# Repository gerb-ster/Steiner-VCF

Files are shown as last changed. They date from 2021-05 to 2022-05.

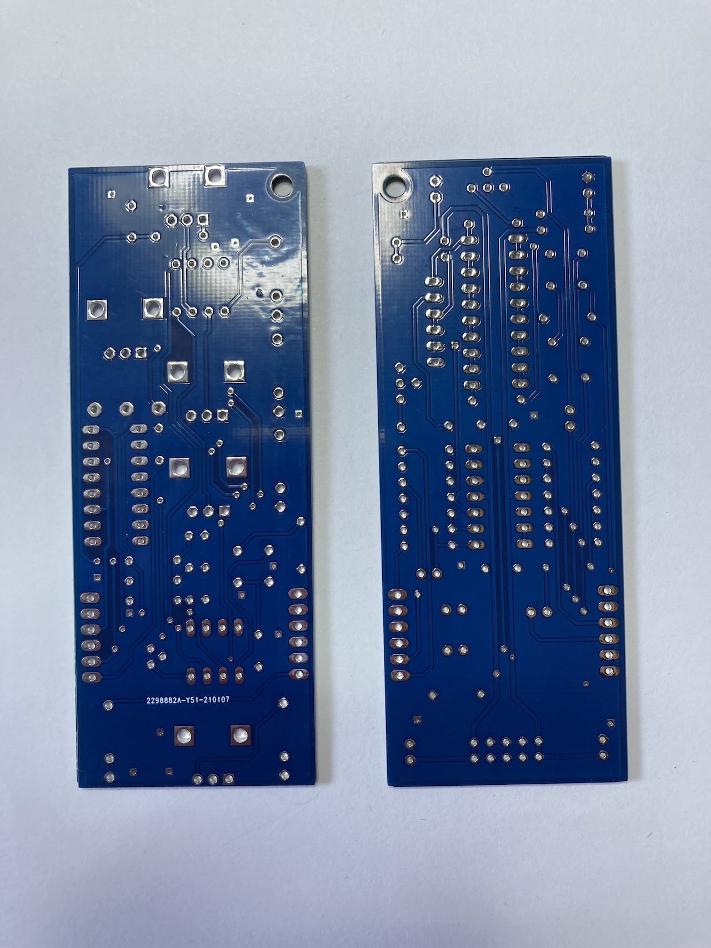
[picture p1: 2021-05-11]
images/IMG_3992.jpeg

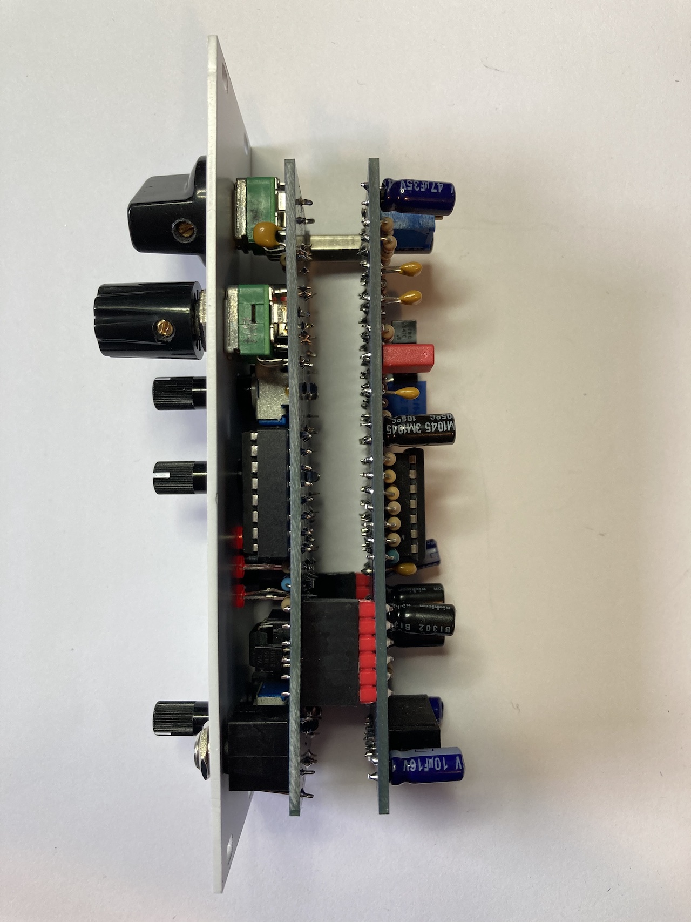
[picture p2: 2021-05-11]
images/IMG_4002.jpeg

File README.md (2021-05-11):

# YUSynth Steiner VCF

Another one of the wonderful VCF designs from YuSynth. The VCF ‘core’ is the same as the design from YuSynth, I just replaced the rotary switch with a ‘digital’ version controlled by a Atmel ATTINY22 and a ADG412 digital SPST switch. This allows you to select 2 more modes, namely HP+BP and LP+BP, next to HP, BP, LP and AP (LP+BP+HP).

The original design:

http://yusynth.net/Modular/EN/STEINERVCF/index-v2.html

## Status: Work in Progress

- done: first schematic & board design
- done: breadboard and test
- done: design frontpanel
- done: order PCB and build prototype
- todo: final debugging
- todo: rewrite the firmware in pure C

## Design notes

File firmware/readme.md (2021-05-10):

## Firmware

The ATTiny IC is loaded up with the Arduino sketch found in this directory

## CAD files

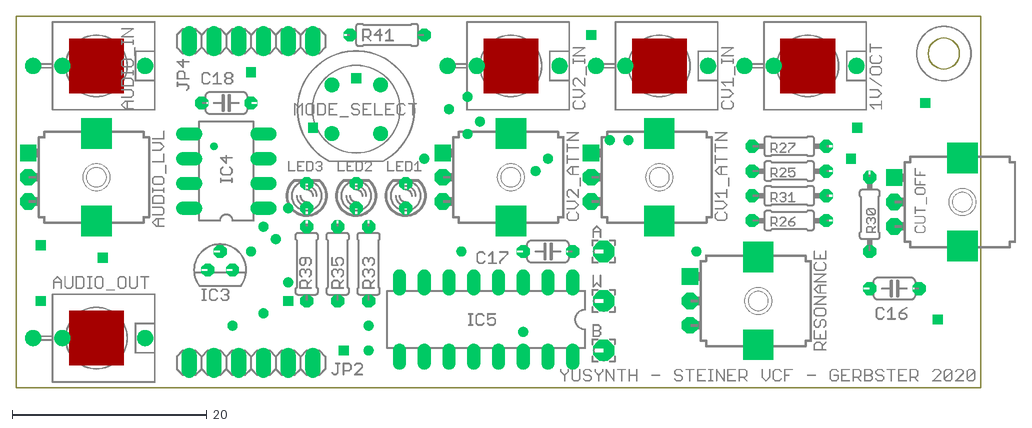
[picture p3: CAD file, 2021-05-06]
faceplates/steiner-vcf-io.dxf
102.7 x 38.1

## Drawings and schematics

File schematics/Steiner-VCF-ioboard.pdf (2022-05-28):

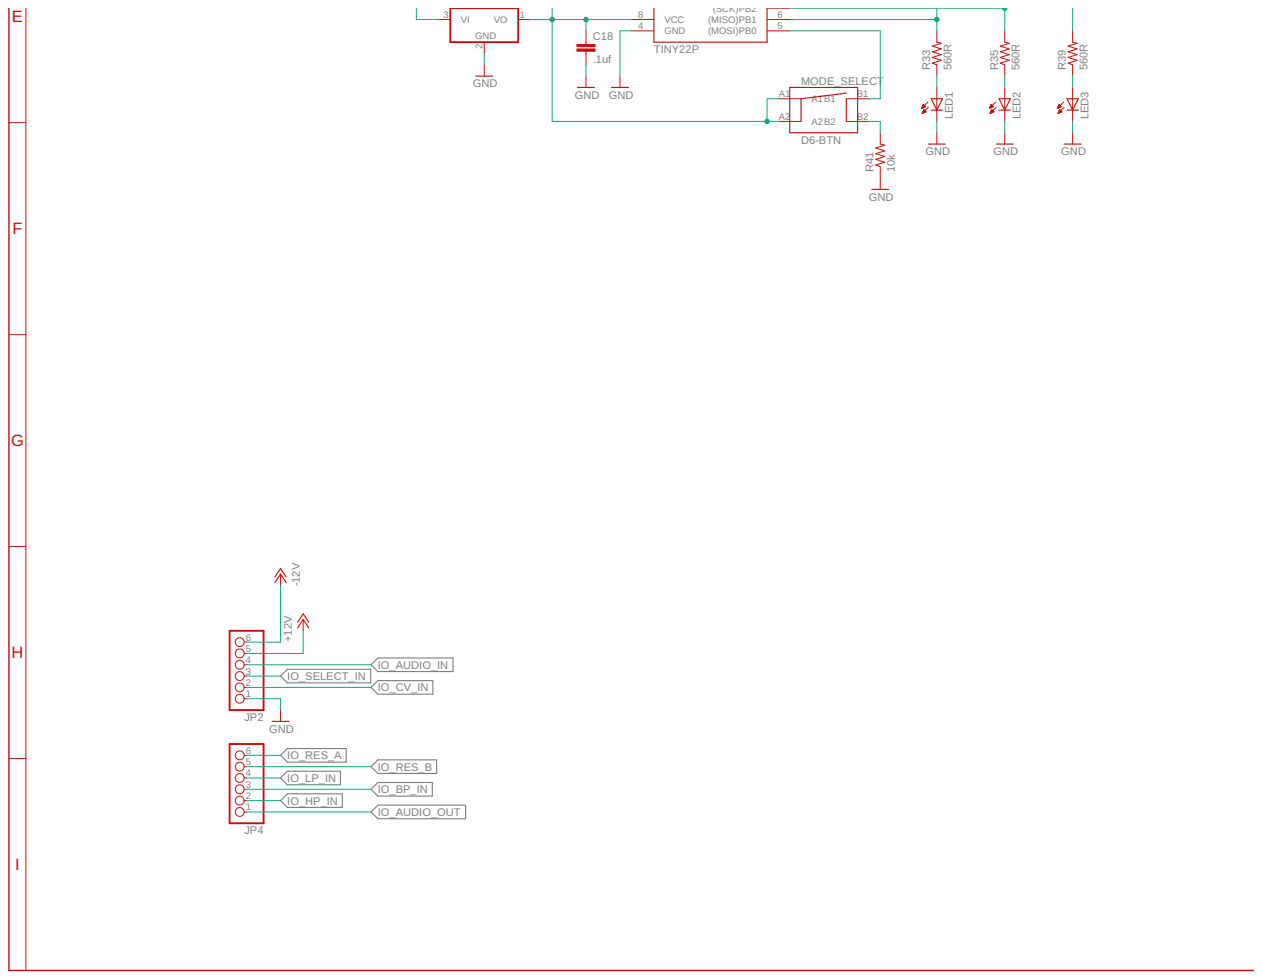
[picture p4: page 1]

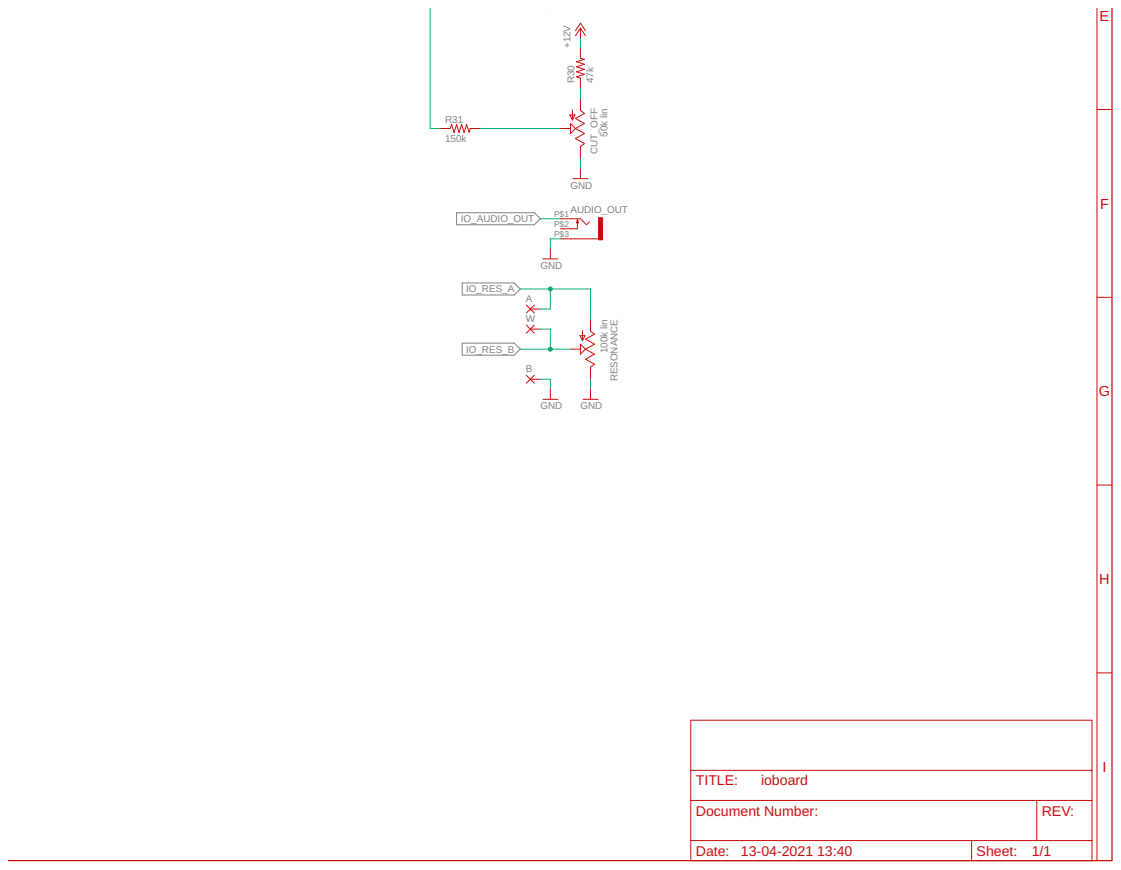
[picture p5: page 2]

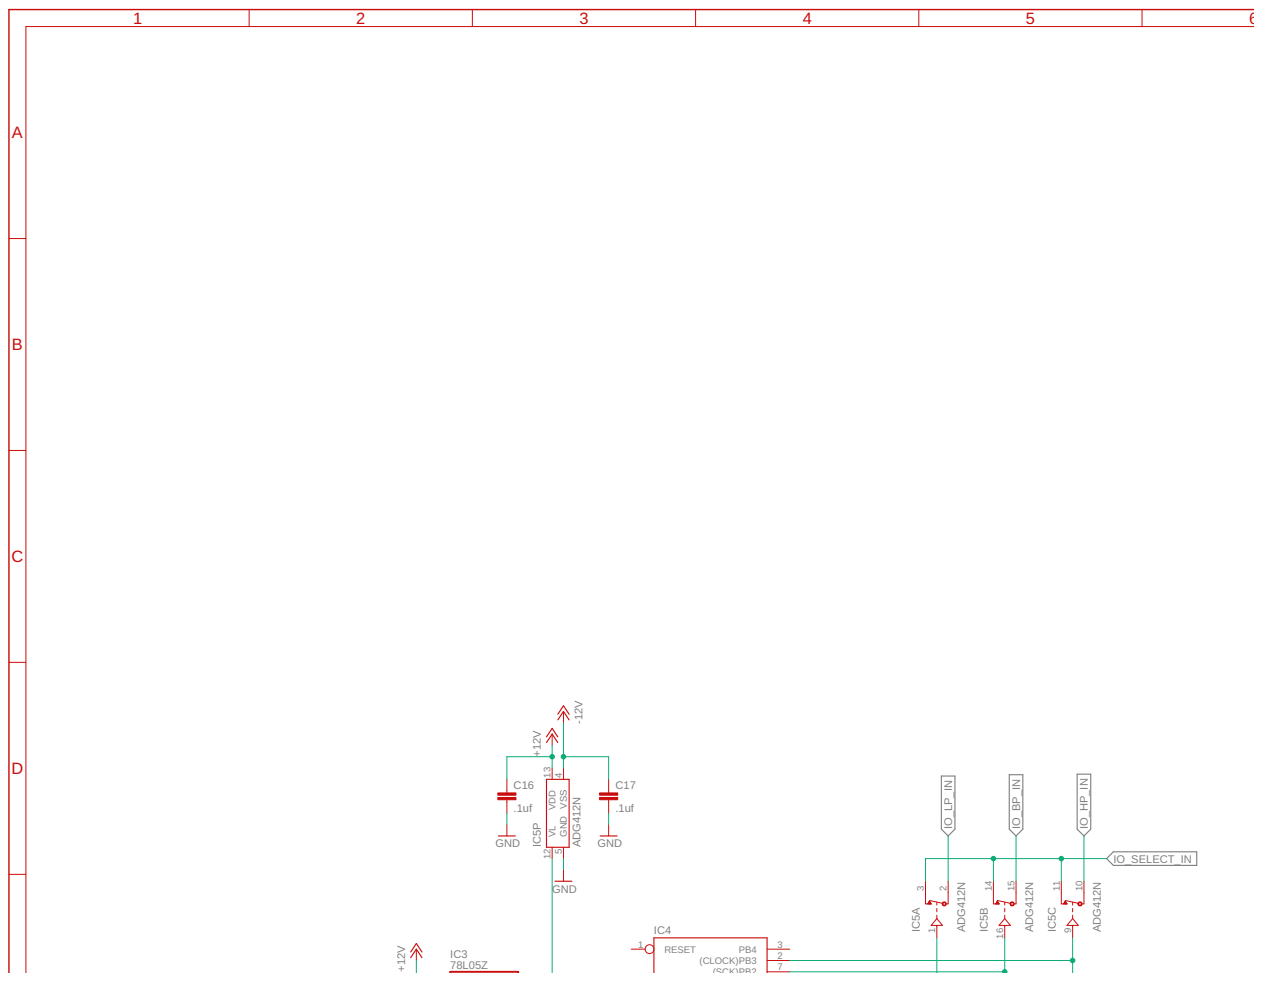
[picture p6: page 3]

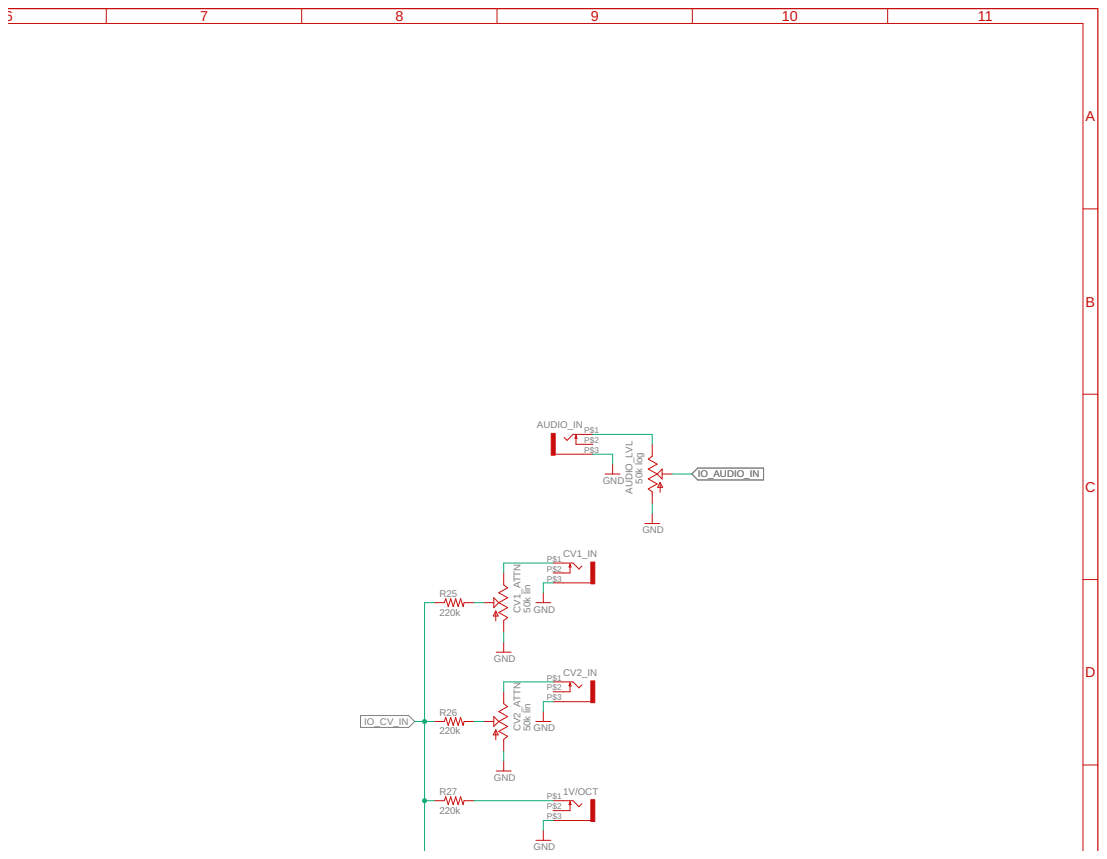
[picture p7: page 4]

50k log 50k lin 50k lin GND GND GND GND GND GND GND 220k 220k 220k ADG412N ADG412N ADG412N f P$3 P$1 P$2 AUDIO_IN P$3 P$1 P$2 CV1_IN P$3 P$1 P$2 CV2_IN P$3 P$1 P$2 1V/OCT AUDIO_LVL CV1_ATTN CV2_ATTN R25 R26 R27 RESET 1 PB4 3 (CLOCK)PB3 2 (SCK)PB2 7 IC4 1 32 IC5A 16 1415 IC5B 9 1110 IC5C IO_HP_IN IO_BP_IN IO_LP_IN IO_AUDIO_IN IO_CV_IN IO_SELECT_IN ABCD 4 5 6 7 8 9 10 11

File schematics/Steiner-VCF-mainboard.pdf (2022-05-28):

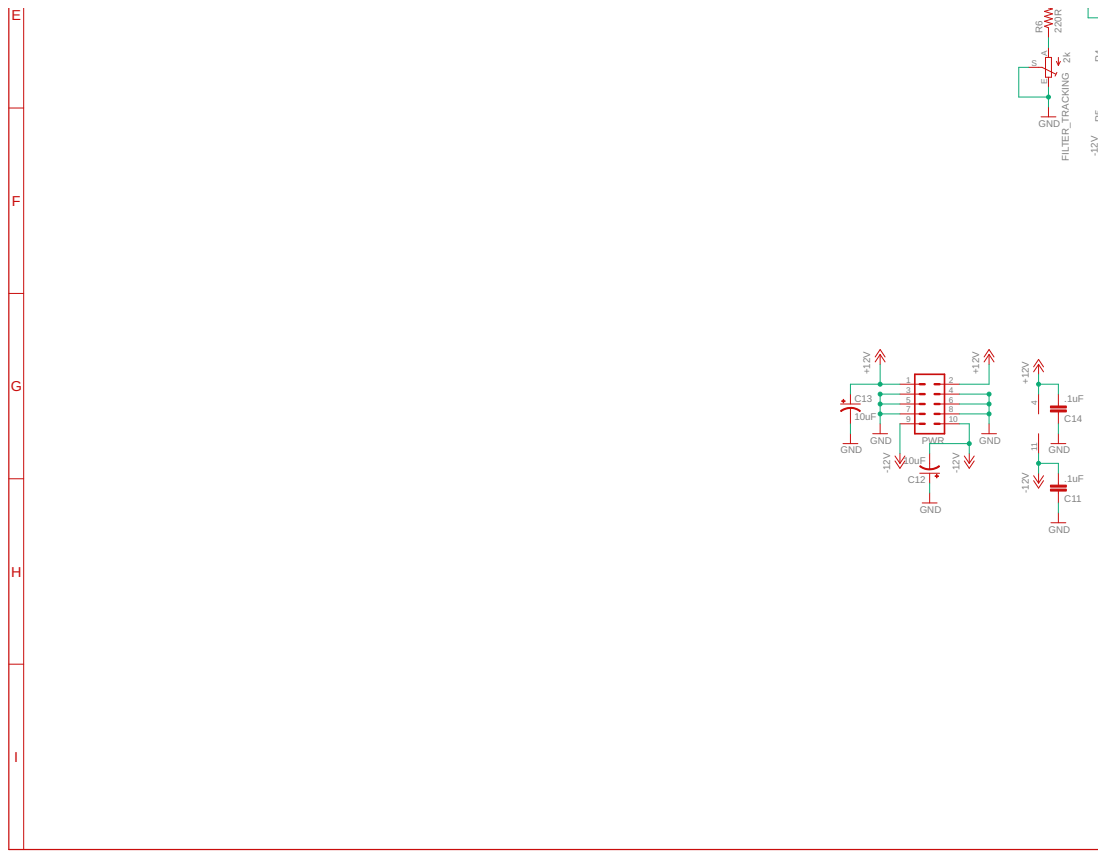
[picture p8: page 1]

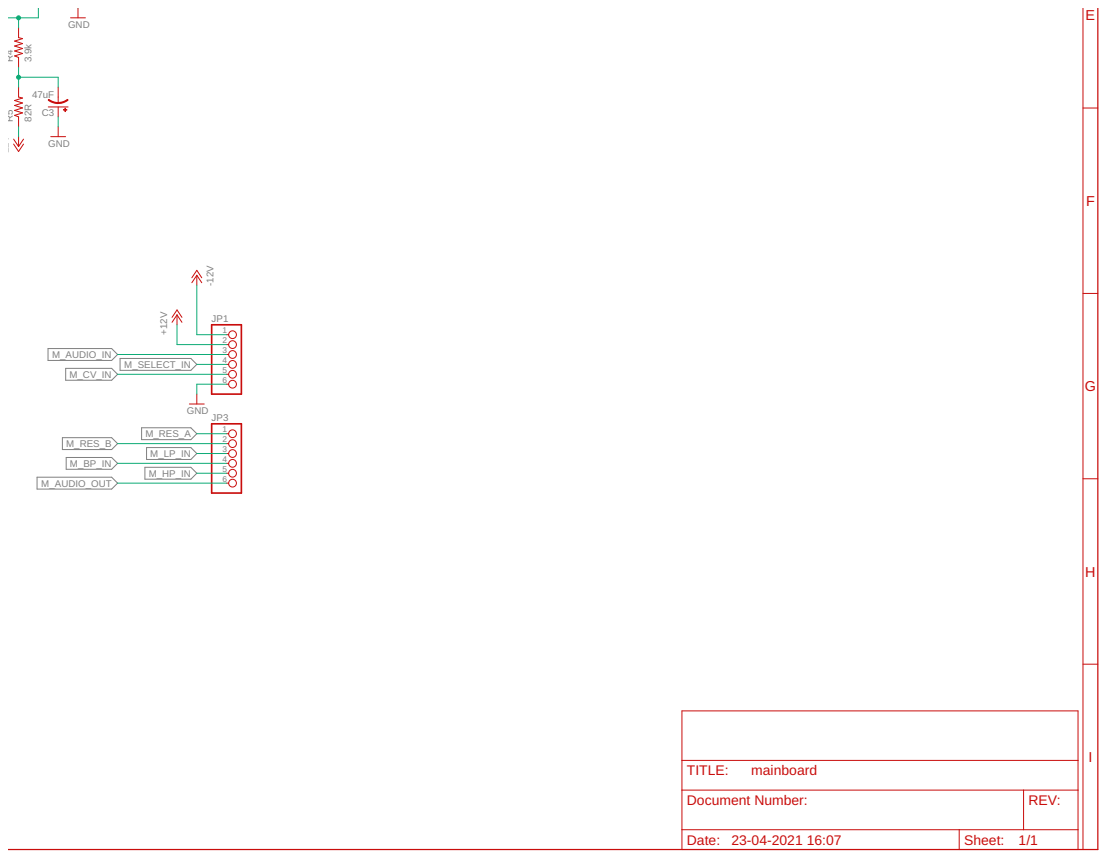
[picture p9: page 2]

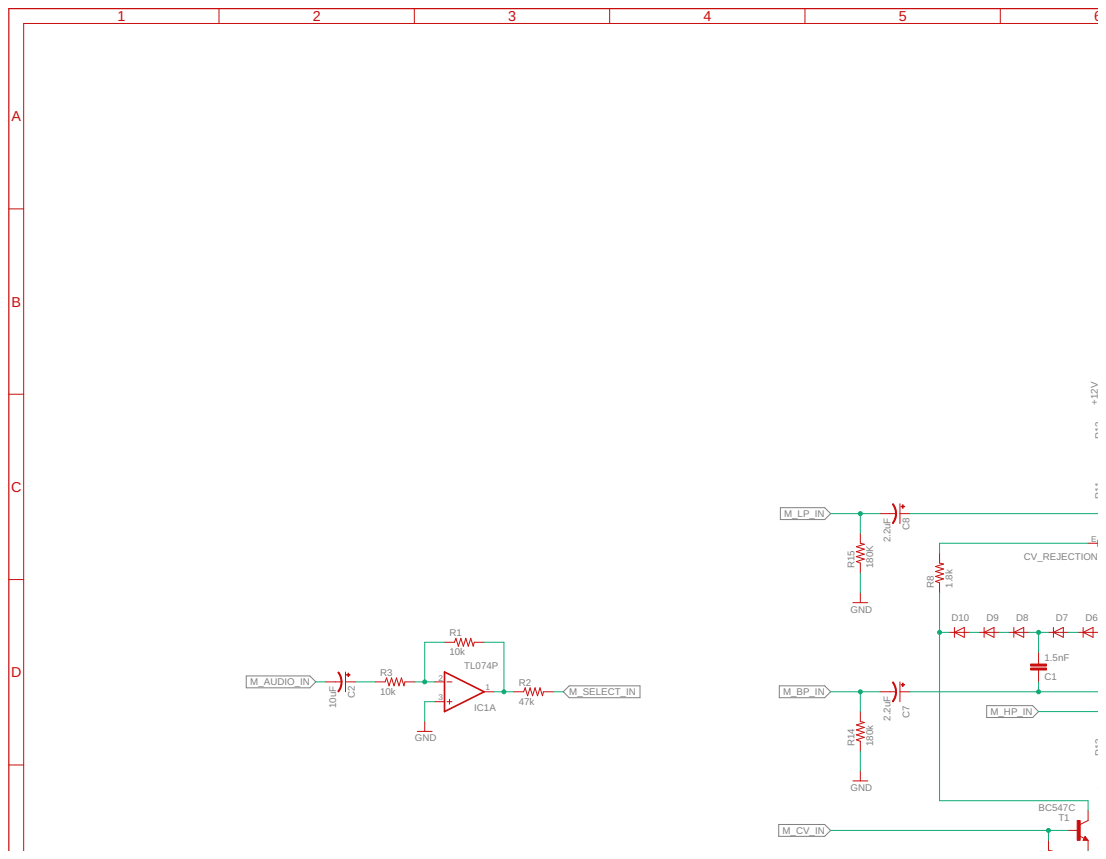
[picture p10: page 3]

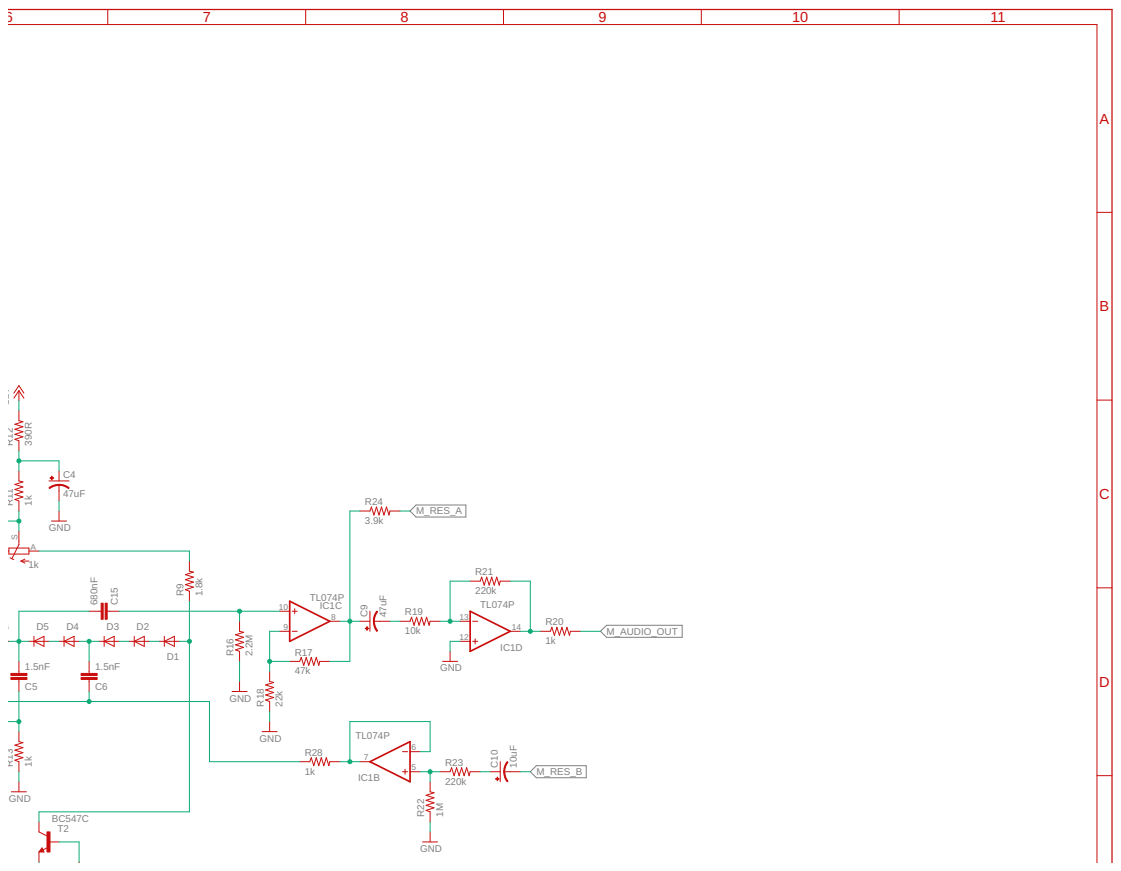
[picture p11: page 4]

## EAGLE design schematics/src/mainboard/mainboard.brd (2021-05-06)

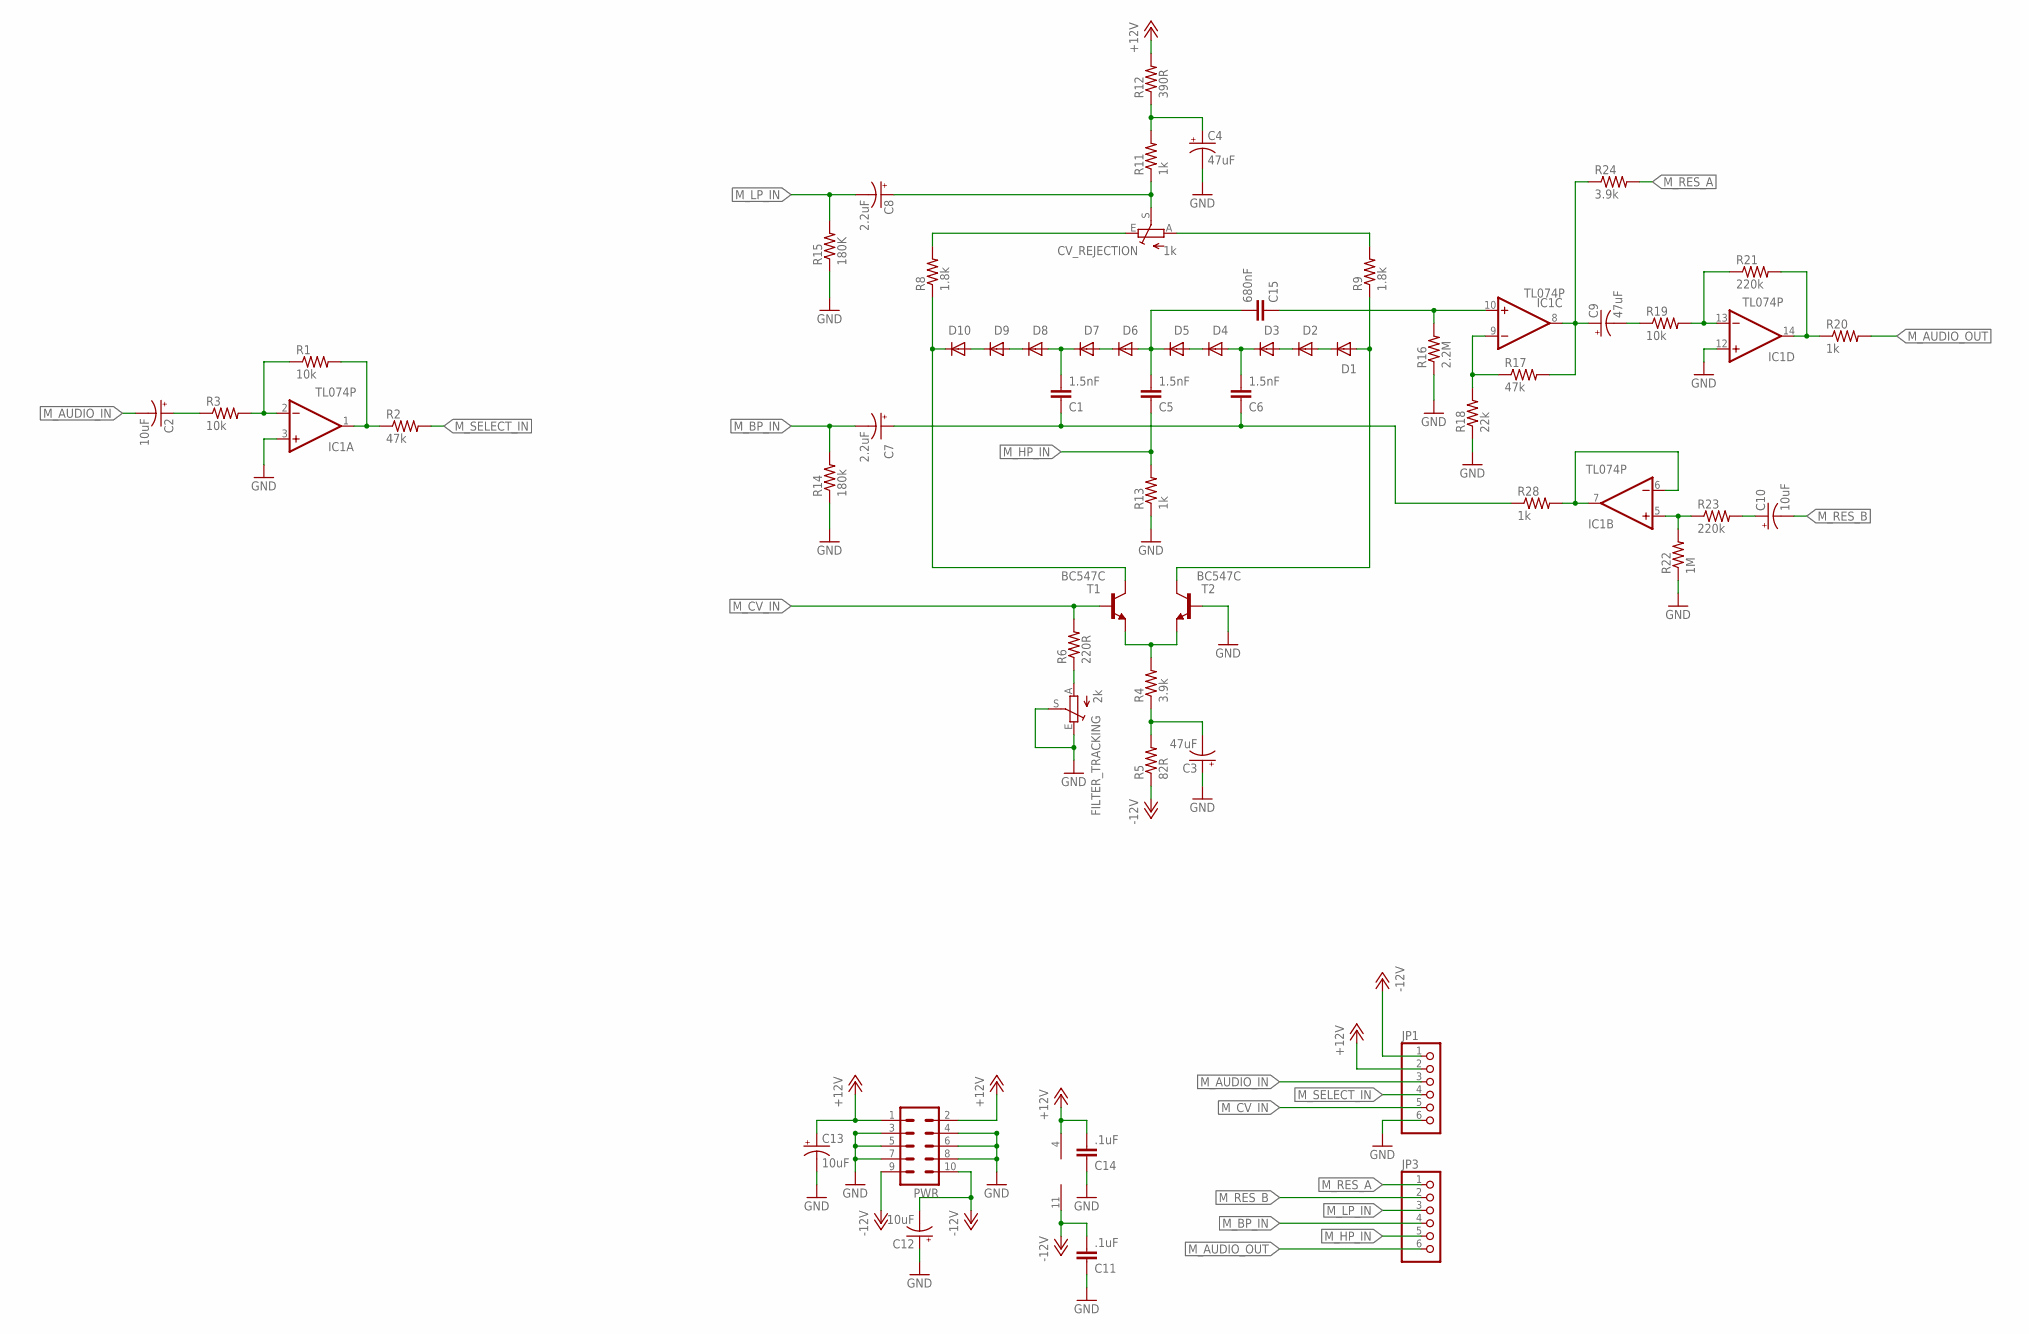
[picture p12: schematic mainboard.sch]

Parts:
C1, C5, C6: 1.5nF; C050-024X044
C2, C10, C12, C13: 10uF; E2,5-5
C3, C4, C9: 47uF; E2,5-5
C7, C8: 2.2uF; E2,5-5
C11, C14: .1uF; C050-024X044
C15: 680nF; C050-035X075
CV_REJECTION: 1k; S64YW
D1, D2, D3, D4, D5, D6, D7, D8, D9, D10: 1N4148DO35-7; DO35-7
FILTER_TRACKING: 2k; S64YW
IC1: TL074P; DIL14
JP1, JP3: PINHD-1X6; 1X06
PWR: ML10
R1, R3, R19: 10k; 0204/7
R2, R17: 47k; 0204/7
R4, R24: 3.9k; 0204/7
R5: 82R; 0204/7
R6: 220R; 0204/7
R8, R9: 1.8k; 0204/7
R11, R13, R20, R28: 1k; 0204/7
R12: 390R; 0204/7
R14: 180k; 0204/7
R15: 180K; 0204/7
R16: 2.2M; 0204/7
R18: 22k; 0204/7
R21, R23: 220k; 0204/7
R22: 1M; 0204/7
T1, T2: BC547C; TO92-CBE

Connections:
+12V: C13.+, C14.1, IC1.4 (V+), JP1.2, PWR.1, PWR.2, R12.2
-12V: C11.1, C12.-, IC1.11 (V-), JP1.1, PWR.9, PWR.10, R5.1
GND: C3.+, C4.-, C11.2, C12.+, C13.-, C14.2, FILTER_TRACKING.E, FILTER_TRACKING.S, IC1.3 (+IN), IC1.12 (+IN), JP1.6, PWR.3, PWR.4, PWR.5, PWR.6, PWR.7, PWR.8, R13.1, R14.1, R15.1, R16.1, R18.1, R22.1, T2.B
M_AUDIO_IN: C2.-, JP1.3
M_AUDIO_OUT: JP3.6, R20.2
M_BP_IN: C7.-, JP3.4, R14.2
M_CV_IN: JP1.5, R6.2, T1.B
M_HP_IN: C5.2, JP3.5, R13.2
M_LP_IN: C8.-, JP3.3, R15.2
M_RES_A: JP3.1, R24.2
M_RES_B: C10.-, JP3.2
M_SELECT_IN: JP1.4, R2.2
unnamed: C2.+, R3.1
unnamed: IC1.2 (-IN), R1.1, R3.2
unnamed: IC1.1 (OUT), R1.2, R2.1
unnamed: C3.-, R4.1, R5.2
unnamed: R4.2, T1.E, T2.E
unnamed: D1.A, R9.1, T2.C
unnamed: FILTER_TRACKING.A, R6.1
unnamed: D10.C, R8.1, T1.C
unnamed: D9.C, D10.A
unnamed: D8.C, D9.A
unnamed: C1.1, D7.C, D8.A
unnamed: D6.C, D7.A
unnamed: C15.2, IC1.10 (+IN), R16.2
unnamed: D4.C, D5.A
unnamed: C6.1, D3.C, D4.A
unnamed: D2.C, D3.A
unnamed: D1.C, D2.A
unnamed: CV_REJECTION.E, R8.2
unnamed: CV_REJECTION.A, R9.2
unnamed: C8.+, CV_REJECTION.S, R11.1
unnamed: C4.+, R11.2, R12.1
unnamed: C1.2, C6.2, C7.+, R28.1
unnamed: IC1.9 (-IN), R17.1, R18.2
unnamed: C9.+, IC1.8 (OUT), R17.2, R24.1
unnamed: IC1.13 (-IN), R19.2, R21.1
unnamed: C9.-, R19.1
unnamed: IC1.5 (+IN), R22.2, R23.1
unnamed: IC1.14 (OUT), R20.1, R21.2
unnamed: C10.+, R23.2
unnamed: IC1.6 (-IN), IC1.7 (OUT), R28.2
unnamed: C5.1, C15.1, D5.C, D6.A

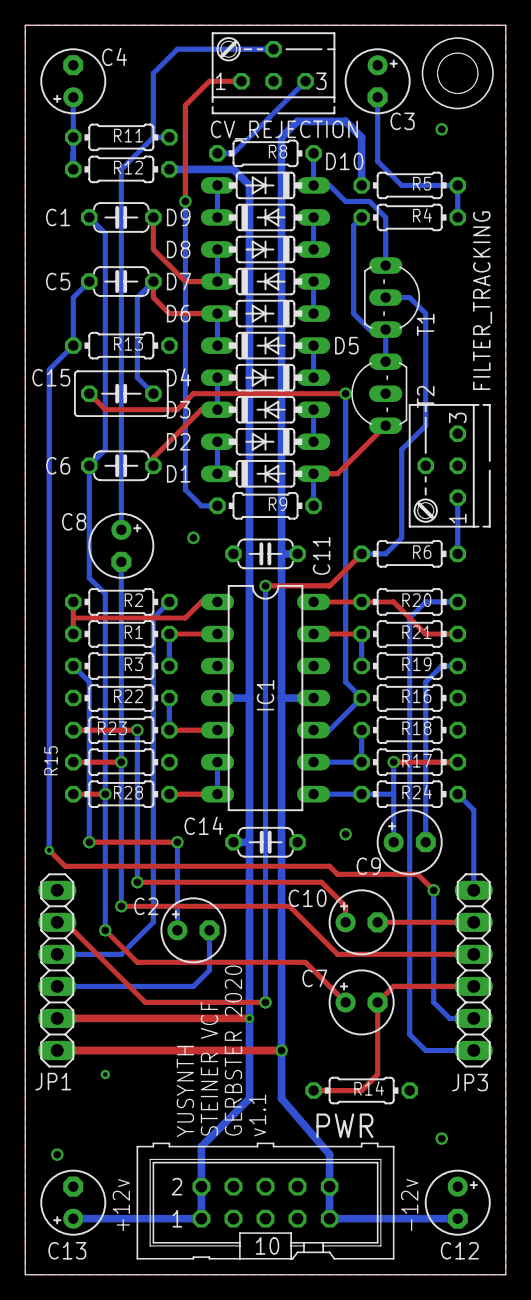
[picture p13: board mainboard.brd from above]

Board: 2 copper layers, 38.1 x 99.1 mm, 56 parts (0 on the bottom side), 43 nets.

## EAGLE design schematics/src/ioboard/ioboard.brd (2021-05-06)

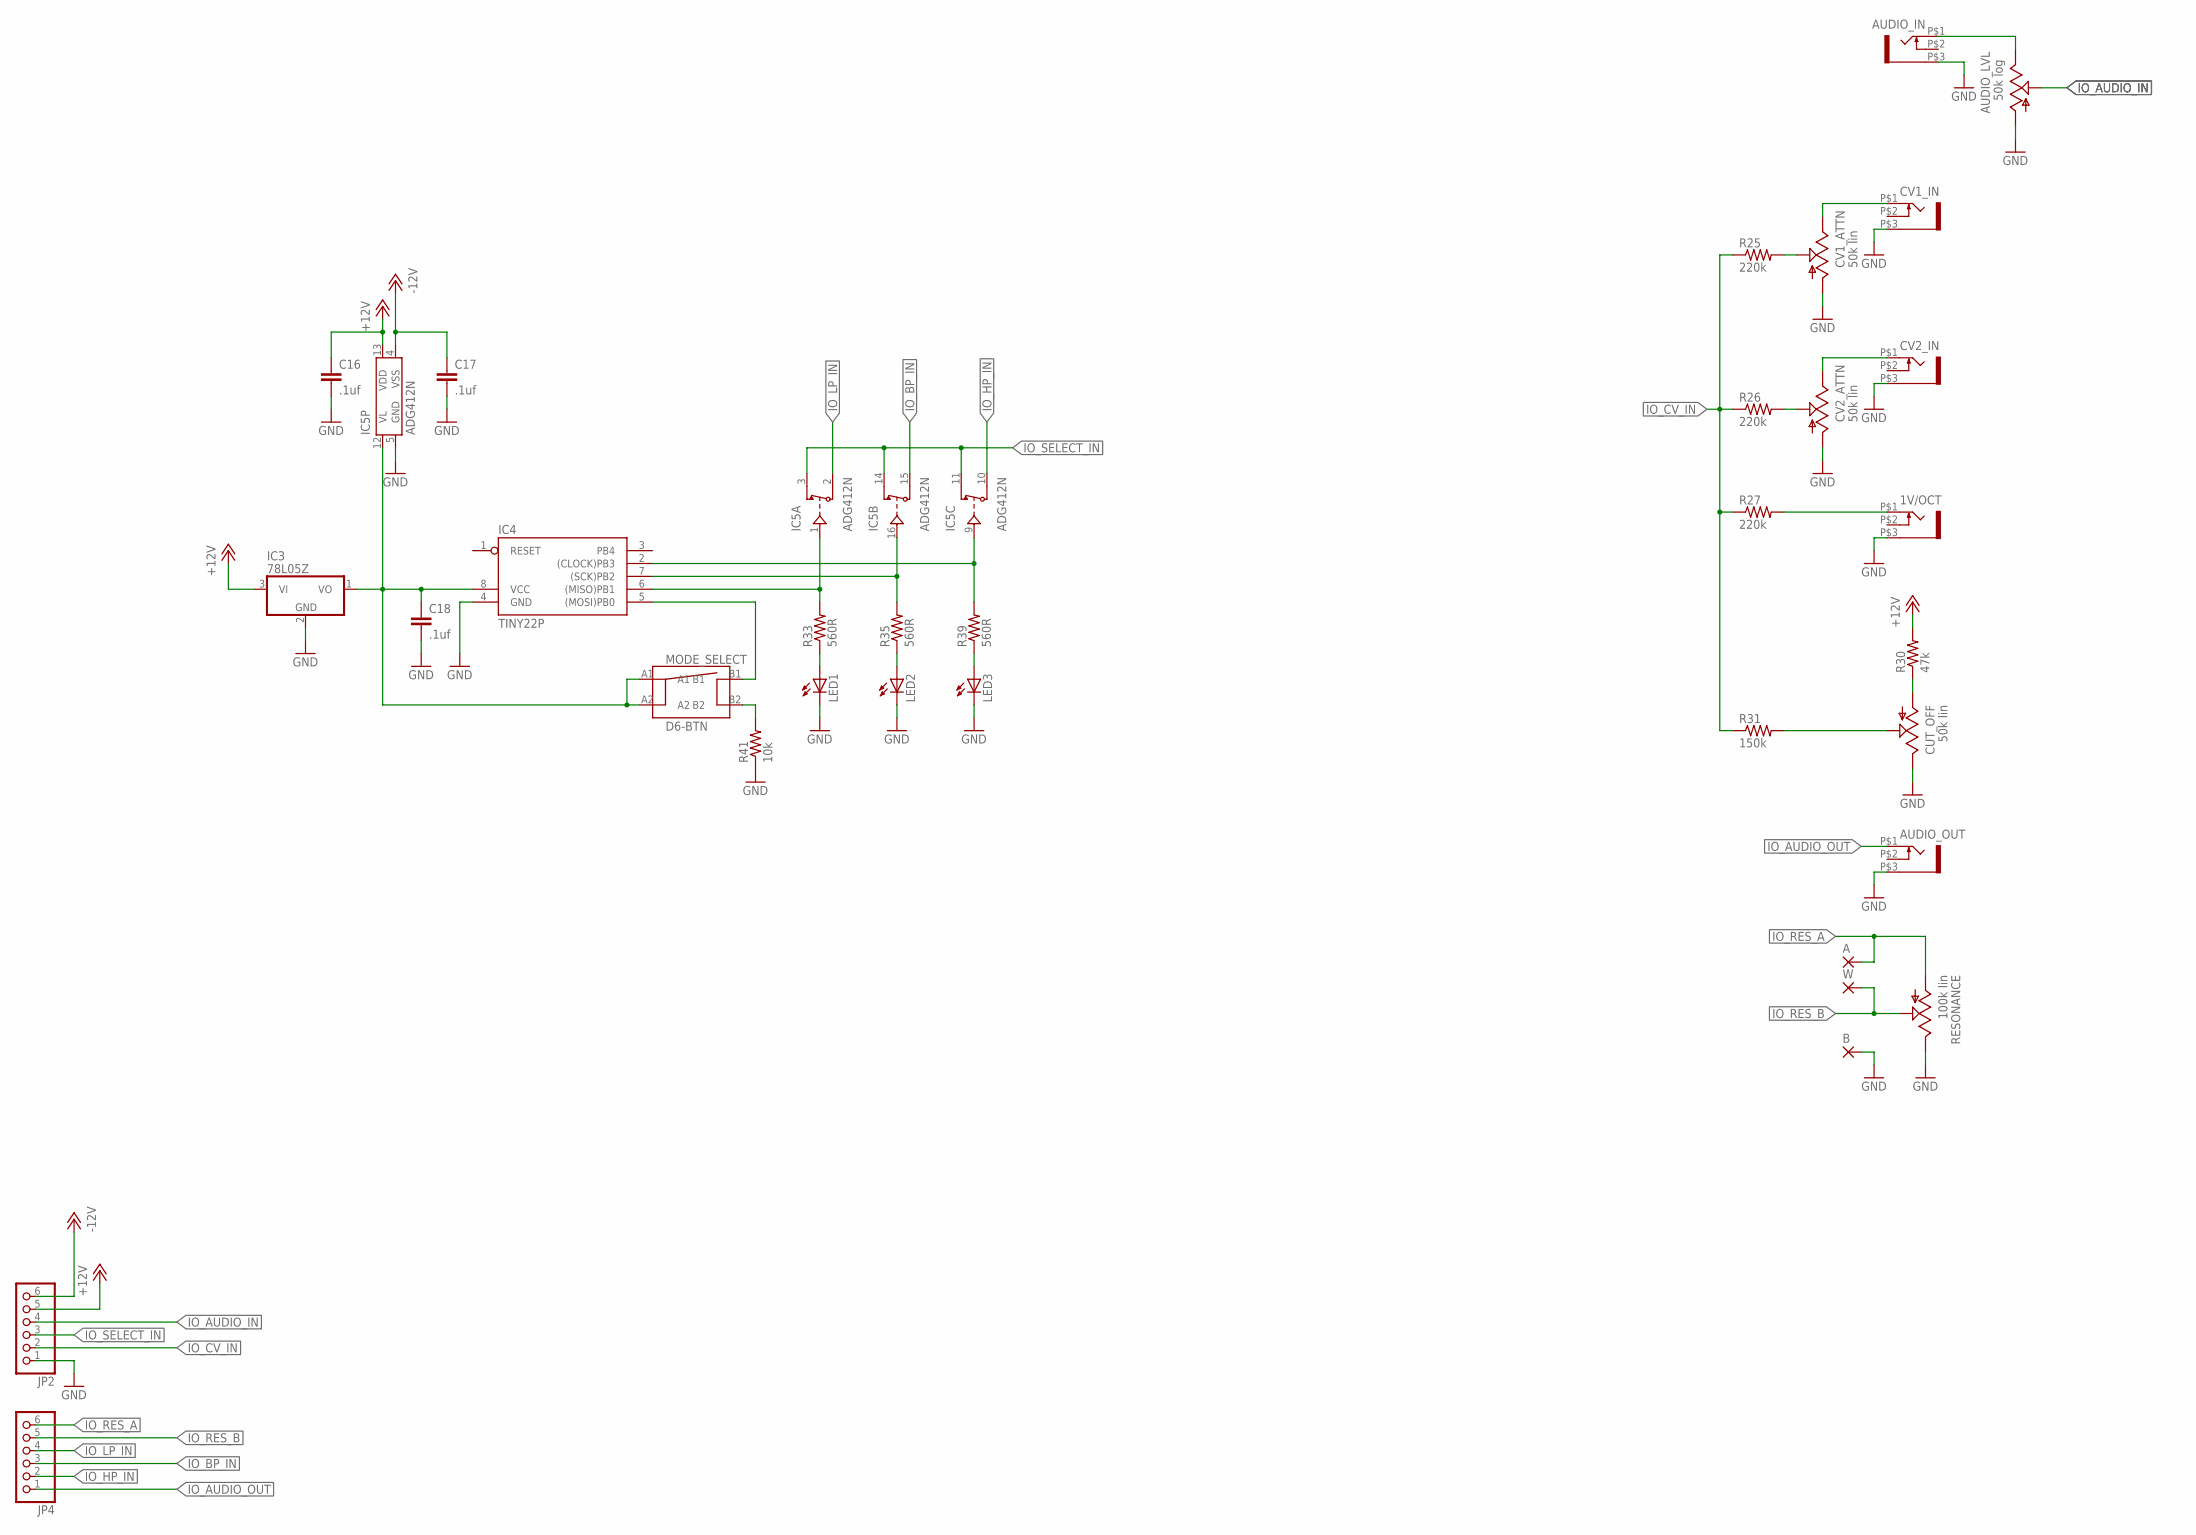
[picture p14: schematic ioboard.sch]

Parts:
1V/OCT: WQP-PJ301M-12_JACK
A: 2,15/1,0
AUDIO_IN: WQP-PJ301M-12_JACK
AUDIO_LVL: 50k log; EVUF
AUDIO_OUT: WQP-PJ301M-12_JACK
B: 2,15/1,0
C16, C17, C18: .1uf; C050-024X044
CUT_OFF: 50k lin; EVUF
CV1_ATTN, CV2_ATTN: 50k lin; EVUF
CV1_IN, CV2_IN: WQP-PJ301M-12_JACK
IC3: 78L05Z; TO92
IC4: TINY22P; DIL08
IC5: ADG412N; DIL16
JP2, JP4: PINHD-1X6; 1X06
LED1, LED2, LED3: LED3MM
MODE_SELECT: D6-BTN
R25, R26, R27: 220k; 0204/7
R30: 47k; 0204/7
R31: 150k; 0204/7
R33, R35, R39: 560R; 0207/7
R41: 10k; 0207/7
RESONANCE: 100k lin; EVUF
W: 2,15/1,0

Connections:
+12V: C16.1, IC3.3 (VI), IC5.13 (VDD), JP2.5, R30.2
-12V: C17.1, IC5.4 (VSS), JP2.6
GND: 1V/OCT.P$3 (1), AUDIO_IN.P$3 (1), AUDIO_LVL.1 (A), AUDIO_OUT.P$3 (1), B.1, C16.2, C17.2, C18.2, CUT_OFF.3 (E), CV1_ATTN.1 (A), CV1_IN.P$3 (1), CV2_ATTN.1 (A), CV2_IN.P$3 (1), IC3.2 (GND), IC4.4 (GND), IC5.5 (GND), JP2.1, LED1.K (C), LED2.K (C), LED3.K (C), R41.1, RESONANCE.3 (E)
IO_A: IC4.6 ((MISO)PB1), IC5.1 (IN), R33.2
IO_AUDIO_IN: AUDIO_LVL.2 (S), JP2.4
IO_AUDIO_OUT: AUDIO_OUT.P$1 (2), JP4.1
IO_B: IC4.7 ((SCK)PB2), IC5.16 (IN), R35.2
IO_BP_IN: IC5.15 (D), JP4.3
IO_CV_IN: JP2.2, R25.1, R26.1, R27.1, R31.1
IO_HP_IN: IC5.10 (D), JP4.2
IO_LP_IN: IC5.2 (D), JP4.4
IO_RES_A: A.1, JP4.6, RESONANCE.1 (A)
IO_RES_B: JP4.5, RESONANCE.2 (S), W.1
IO_SELECT_IN: IC5.3 (S), IC5.11 (S), IC5.14 (S), JP2.3
unnamed: MODE_SELECT.B2, R41.2
unnamed: C18.1, IC3.1 (VO), IC4.8 (VCC), IC5.12 (VL), MODE_SELECT.A1, MODE_SELECT.A2
unnamed: IC4.2 ((CLOCK)PB3), IC5.9 (IN), R39.2
unnamed: AUDIO_IN.P$1 (2), AUDIO_LVL.3 (E)
unnamed: LED1.A, R33.1
unnamed: CV1_ATTN.2 (S), R25.2
unnamed: CV2_ATTN.2 (S), R26.2
unnamed: CV1_ATTN.3 (E), CV1_IN.P$1 (2)
unnamed: LED2.A, R35.1
unnamed: LED3.A, R39.1
unnamed: CV2_ATTN.3 (E), CV2_IN.P$1 (2)
unnamed: IC4.5 ((MOSI)PB0), MODE_SELECT.B1
unnamed: CUT_OFF.1 (A), R30.1
unnamed: 1V/OCT.P$1 (2), R27.2
unnamed: CUT_OFF.2 (S), R31.2

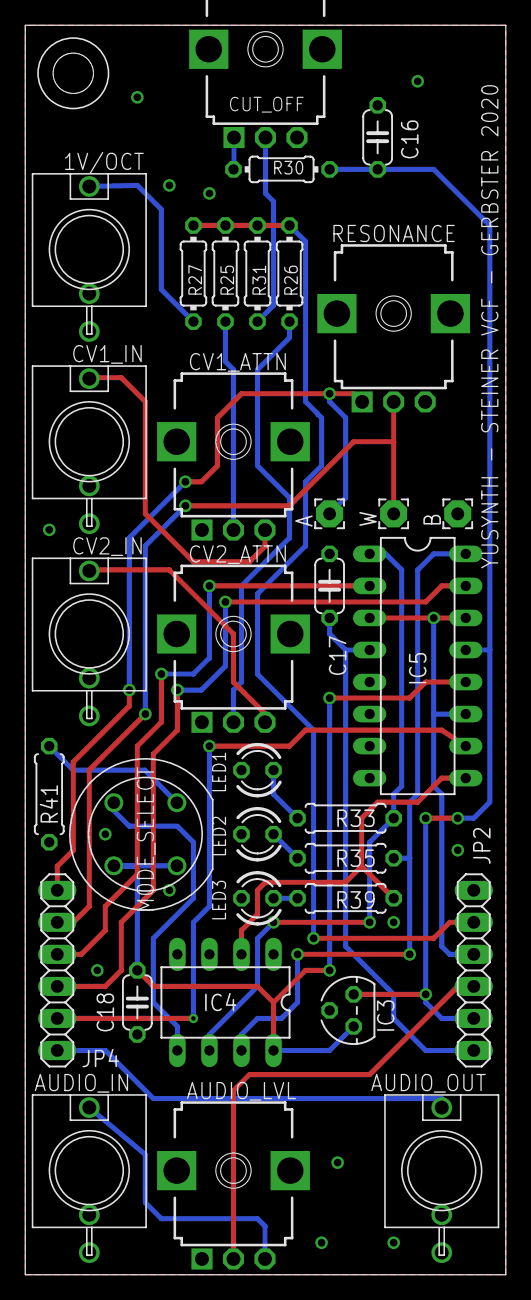
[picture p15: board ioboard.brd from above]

Board: 2 copper layers, 38.1 x 99.1 mm, 34 parts (0 on the bottom side), 29 nets.

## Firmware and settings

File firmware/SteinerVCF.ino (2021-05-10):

#define LP 0
#define BP 1
#define HP 2
#define LP_HP 3
#define LP_BP 4
#define BP_HP 5

#define MODE_COUNT 6

#define BTN_PORT 0
#define LP_PORT 1
#define BP_PORT 2
#define HP_PORT 3

int button_state;
int last_button_state = LOW;

unsigned long last_debounce_time = 0;
unsigned long debounce_delay = 50;

int current_mode = 0;

int enable_mode(int mode)
{
  // set all to low
  digitalWrite(LP_PORT, LOW);
  digitalWrite(BP_PORT, LOW);
  digitalWrite(HP_PORT, LOW);

  // set selected mode
  switch(mode)
  {
    case LP:
      digitalWrite(LP_PORT, HIGH);
    break;

    case BP:
      digitalWrite(BP_PORT, HIGH);
    break;

    case HP:
      digitalWrite(HP_PORT, HIGH);
    break;

    case LP_HP:
      digitalWrite(LP_PORT, HIGH);
      digitalWrite(HP_PORT, HIGH);
    break;

    case LP_BP:
      digitalWrite(LP_PORT, HIGH);
      digitalWrite(BP_PORT, HIGH);
    break;

    case BP_HP:
      digitalWrite(BP_PORT, HIGH);
      digitalWrite(HP_PORT, HIGH);
    break;
  }
}

void setup() 
{
  // button port
  pinMode(BTN_PORT, INPUT);

  // output port
  pinMode(LP_PORT, OUTPUT);
  pinMode(BP_PORT, OUTPUT);
  pinMode(HP_PORT, OUTPUT);

  // start
  enable_mode(current_mode);
}

void loop() 
{
  int reading = digitalRead(0);

  if (reading != last_button_state)
  {
    last_debounce_time = millis();
  }
  
  if ((millis() - last_debounce_time) > debounce_delay) 
  {
    if (reading != button_state)
    {
      button_state = reading;

      if (button_state == HIGH) 
      {
        current_mode++;

        if(current_mode == MODE_COUNT)
        {
          current_mode = 0;
        }
        
        enable_mode(current_mode);
      }
    }
  }

  last_button_state = reading;
}

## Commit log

2021-05-06 some files
    [SteinerVCF.brd, SteinerVCF.sch, steiner-vcf-io.dxf]
2021-05-07 Added files & structure
    [Steiner-VCF-ioboard.GBL, Steiner-VCF-ioboard.GBO, Steiner-VCF-ioboard.GBP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]
2021-08-06 Updated some schematics and docs
    [Steiner-VCF-ioboard.GBL, Steiner-VCF-ioboard.GBO, Steiner-VCF-ioboard.GBP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]
2021-08-10 Fixed some bugs and updated documentation
    [Steiner-VCF-ioboard.XLN, Steiner-VCF-mainboard.XLN, gerber_job.gbrjob]
2022-04-20 Some updates & bugfixes
    [Steiner-VCF-ioboard.XLN, Steiner-VCF-mainboard.XLN, gerber_job.gbrjob]
2022-04-22 Fixed schematics & descriptions
    [Steiner-VCF-ioboard.XLN, Steiner-VCF-mainboard.XLN, gerber_job.gbrjob]
2022-05-17 Updated Firmware
    [Steiner-VCF-ioboard.XLN, Steiner-VCF-mainboard.XLN, gerber_job.gbrjob]
2022-05-18 Updated Faceplates
    [Steiner-VCF-ioboard.XLN, Steiner-VCF-mainboard.XLN, gerber_job.gbrjob]
2022-05-18 Fixed issues
    [Steiner-VCF-ioboard.XLN, Steiner-VCF-mainboard.XLN, gerber_job.gbrjob]
2022-05-21 Fixed schematics
    [Steiner-VCF-ioboard.XLN, Steiner-VCF-mainboard.XLN, gerber_job.gbrjob]
2022-05-28 General updates
    [Steiner-VCF-ioboard.GKO, Steiner-VCF-mainboard.GKO, copper_bottom.gbr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]
